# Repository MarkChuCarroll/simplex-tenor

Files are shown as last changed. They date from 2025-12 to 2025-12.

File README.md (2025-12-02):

# Mini-Tenor Guitar

3d image of the tenor guitar

This is a mini-sized 4-string tenor guitar, intended to be strung using either nylon strings, or extra-light
gauge metal strings.

Everything is printed, _except_:

* a set of tuners with 10mm posts. (I use [these](https://www.amazon.com/gp/product/B0789YL6JF/ref=ppx_yo_dt_b_search_asin_image?ie=UTF8&psc=1).)
* A set of light or extra-light steel tenor banjo or tenor guitar strings. These should
  be strings intended for a CGDA tuning.
* A 12 1/4 inch truss rod (I used [this from StewMac](https://www.amazon.com/gp/product/B07HPBZ3NH/ref=ox_sc_act_title_1?smid=A1BA2XBPZFTT2S&psc=1)).
* 2 m4x60mm screws to attach the neck to the body.
* 2 m4 hex nuts.
* a 4x1mm carbon fiber rod, used to reinforce the body inside of the vertical brace.

Assembly should be pretty obvious.

I recommend printing this from PLA. In my experiments, PLA is by far the
best material that I've tried. PETG has too much flexibility, which seems
to absorb some of the resonant vibrations in the body; ABS adhesion issues
leave tiny micro-gaps in the body which completely ruin the tone.

## The Model

I started with a model written in standard OpenSCAD. That was a bit of a mess; I rewrote it partially using the BOSL libraries for OpenSCAD, which was a big improvement, but I was still struggling to make it come out the way I wanted, because honestly, OpenSCAD is a pretty terrible language.

So I wrote my own 3d modelling language.

The latest version is implemented in [Simplex](https://github.com/MarkChuCarroll/simplex), a 3d modelling
language that I built on top of the Manifest library. This
version of the model is contained in the file "mtenor.s3d".

The running the simplex model through the interpreter, you'll
get a collection of products:

* `mtenor-out-body-tail.stl`: the bottom-most section of the body.
* `mtenor-out-body-center.stl`:  the center section of the body.
* `mtenor-out-body-neck.stl`: The section of the body where the neck
  is attached.
* `mtenor-out-fretboard-full.stl`: a single-piece fretboard for large printers.
* `mtenor-out-fretboard-[ab].stl`: the fretboard split into two pieces for
   printing on normal-sized 3d printers. This includes guide-holes where
   you can insert 5mm pieces of filament as alignment guides, and cutouts
   for registration/alignment with the neck. The registration pegs are
   included in `mtenor-out-mist_bits.stl`.
* `mtenor-out-neck-[abc].stl`: the neck, divided into three printable pieces.
  Like the fretboard, this includes registration holes to use filament to
  align the sections for gluing.
* `mtenor-out-misc_bits.stl`: support plates, registration pegs, and fretboard
  inlays for assembly/glue-up.
* `mtenor-out-assembled.stl`: An image of the fully-assembled guitar, to show
  how the pieces should line up.
* `mtenor-out-bridge.stl`: a set of three different bridges; choose the one that
  gives you the most comfortable string-action.
* `mtenor-out-stand.stl`: a work-in-progress stand for supporting the guitar
  when you're not playing it.

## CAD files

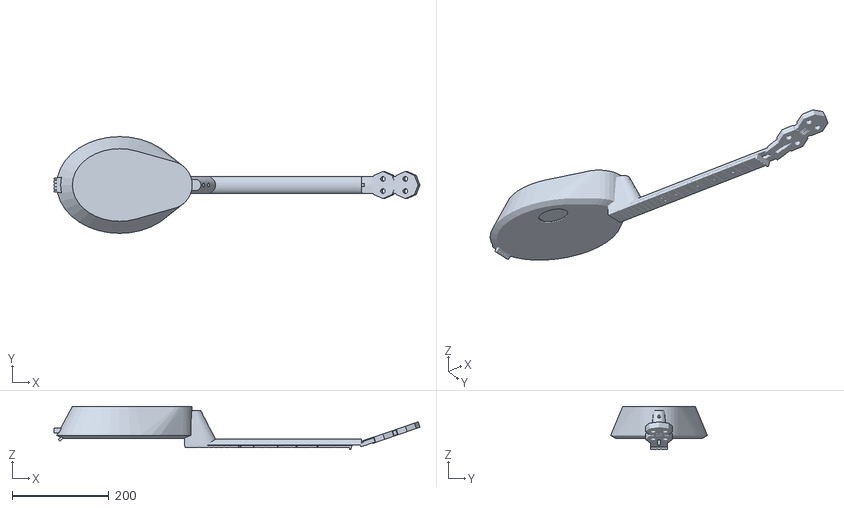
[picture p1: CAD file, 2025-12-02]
mtenor-out-assembled.stl
756.2 x 200.0 x 89.5

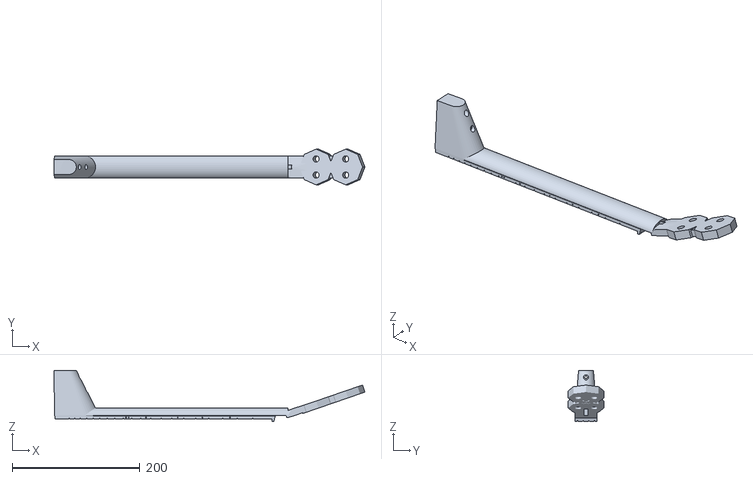
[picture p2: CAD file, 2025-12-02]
mtenor-out-fretboard-full.stl
487.5 x 56.0 x 80.5

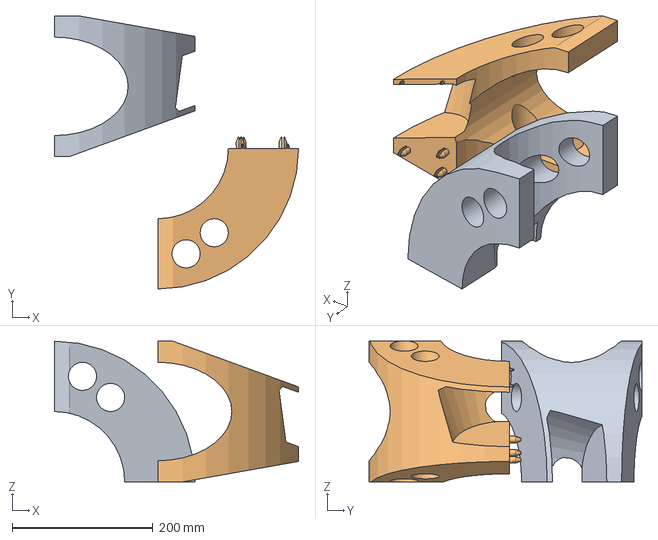
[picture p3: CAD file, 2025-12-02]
mtenor-out-neck-a.3mf
347.4 x 388.2 x 200.0 mm
mtenor-out-stand.stl x 2

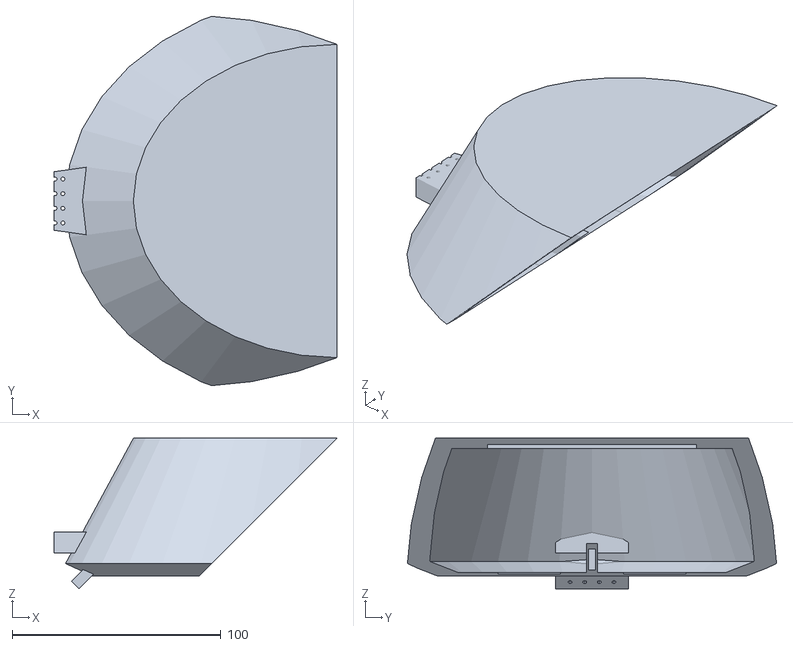
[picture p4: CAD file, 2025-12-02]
mtenor-out-body-tail.stl
135.5 x 176.8 x 72.1

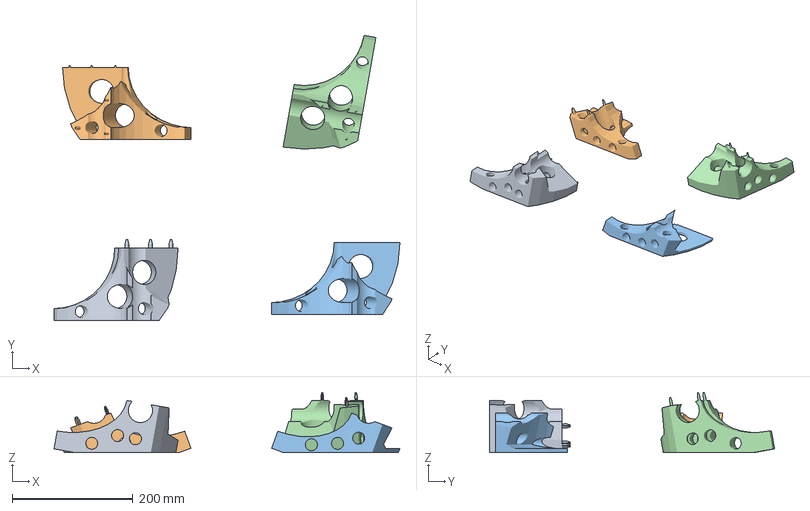
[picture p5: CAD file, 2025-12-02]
split-stand.3mf
573.4 x 472.7 x 99.8 mm
mtenor-out-stand-1.stl
mtenor-out-stand-2.stl
mtenor-out-stand-3.stl
mtenor-out-stand-4.stl

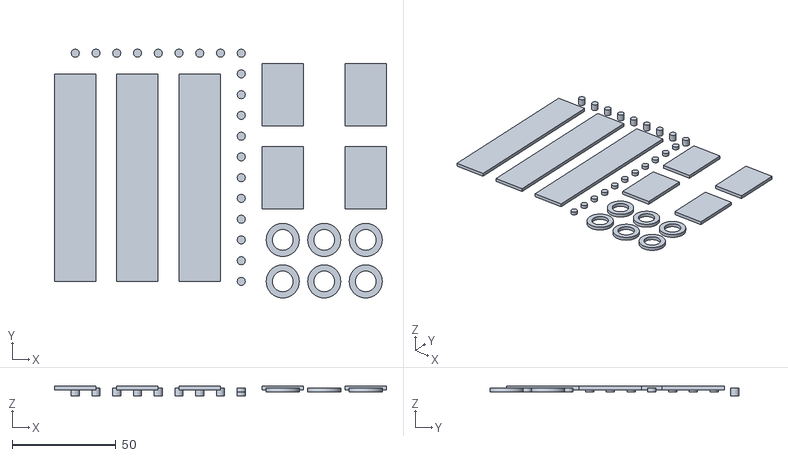
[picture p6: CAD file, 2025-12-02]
mtenor-out-misc_bits.stl
160.0 x 120.0 x 5.00

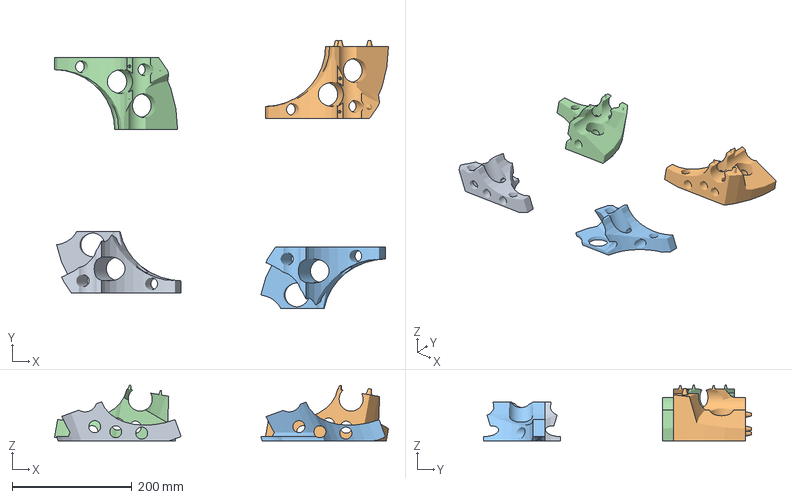
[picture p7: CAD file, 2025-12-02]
mtenor-out-stand-improved.3mf
557.9 x 447.3 x 93.3 mm
mtenor-out-stand.stl x 4

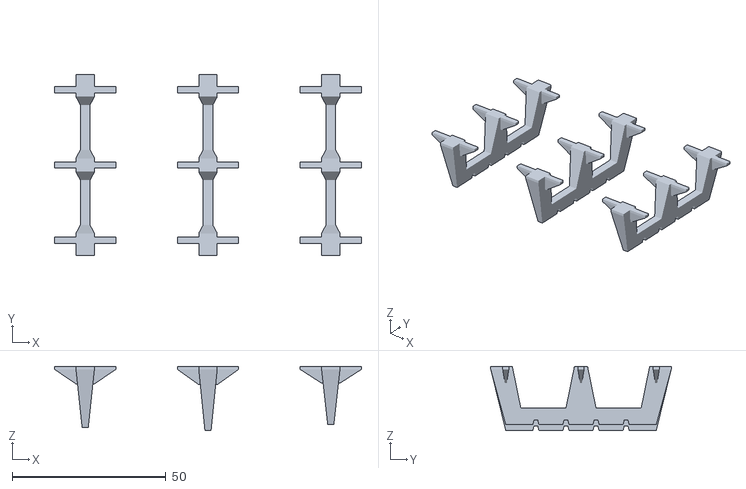
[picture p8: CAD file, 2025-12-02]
mtenor-out-bridge.stl
100.0 x 58.8 x 21.0

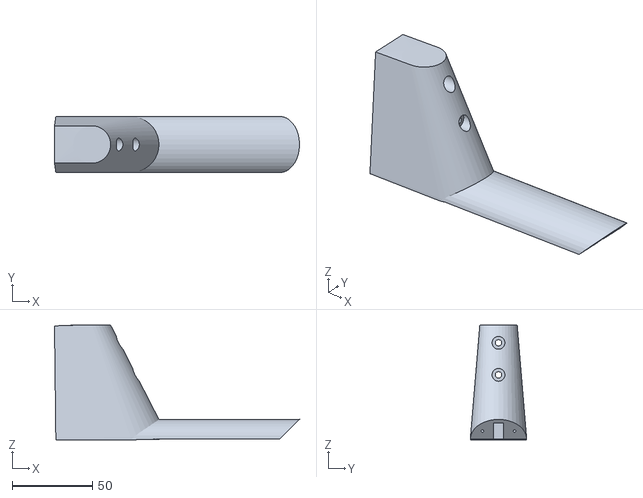
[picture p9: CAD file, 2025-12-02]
mtenor-out-neck-c.stl
152.7 x 35.0 x 71.5

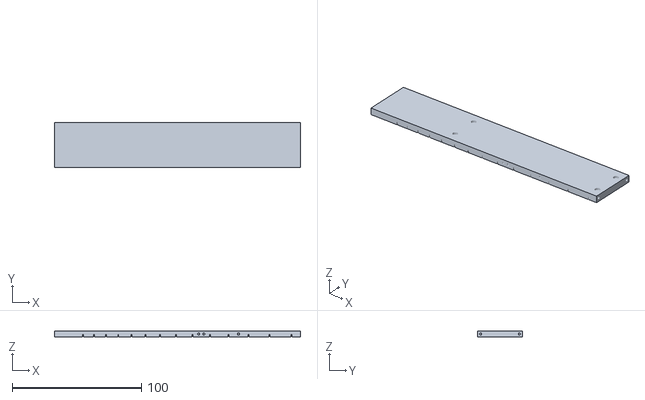
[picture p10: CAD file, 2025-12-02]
mtenor-out-fretboard-b.stl
190.1 x 35.0 x 5.00

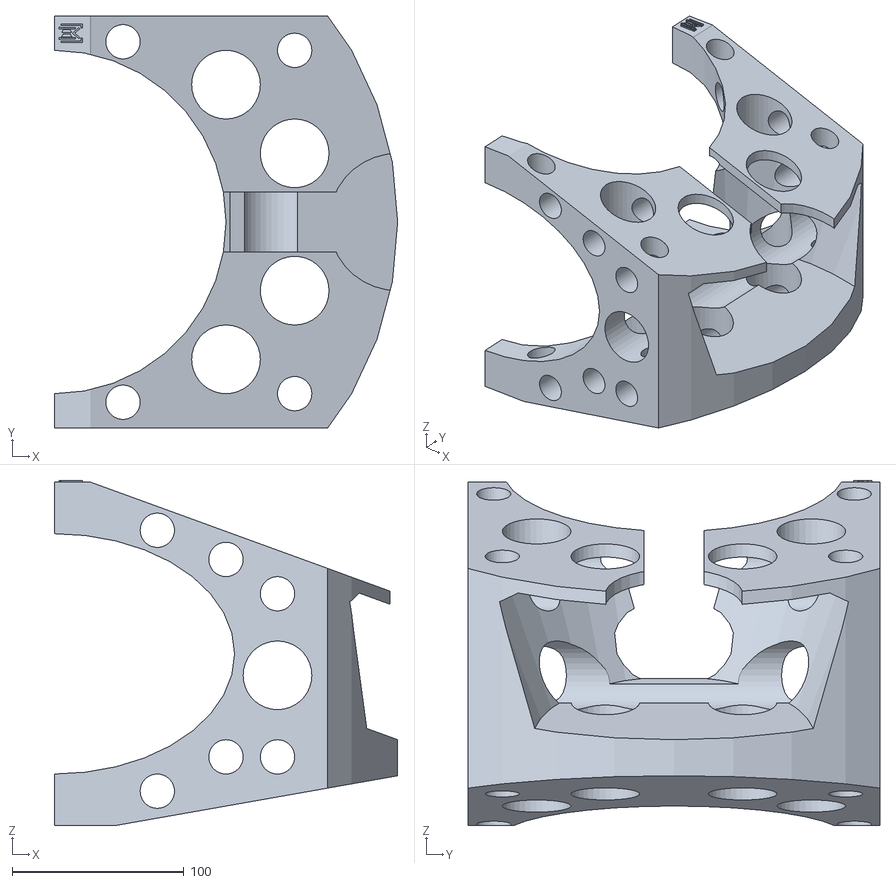
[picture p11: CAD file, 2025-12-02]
mtenor-out-stand.stl
200.0 x 240.0 x 201.0

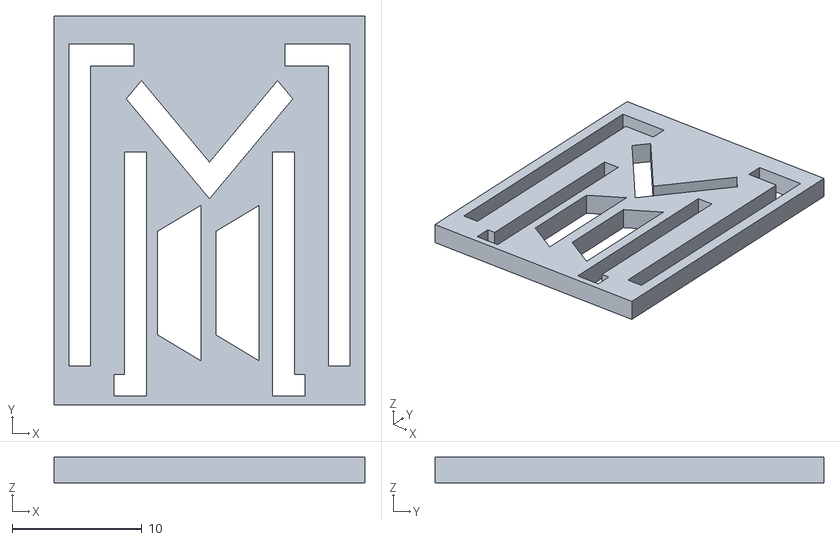
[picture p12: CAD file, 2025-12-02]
mark-out-plate.stl
24.0 x 30.0 x 2.00

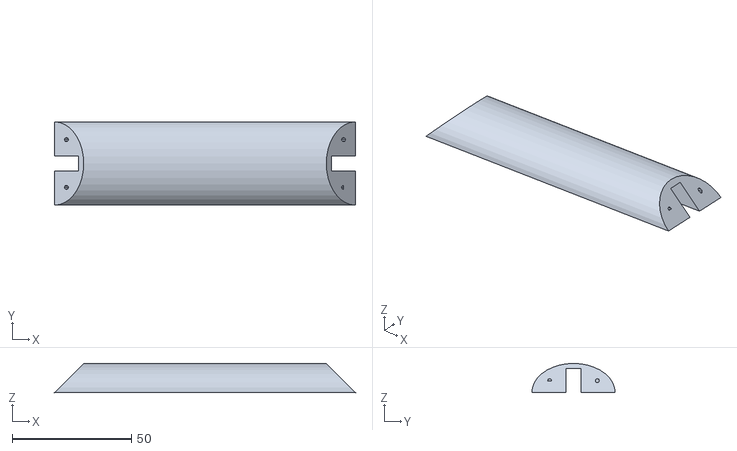
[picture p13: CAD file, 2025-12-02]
mtenor-out-neck-b.stl
126.4 x 35.0 x 12.2

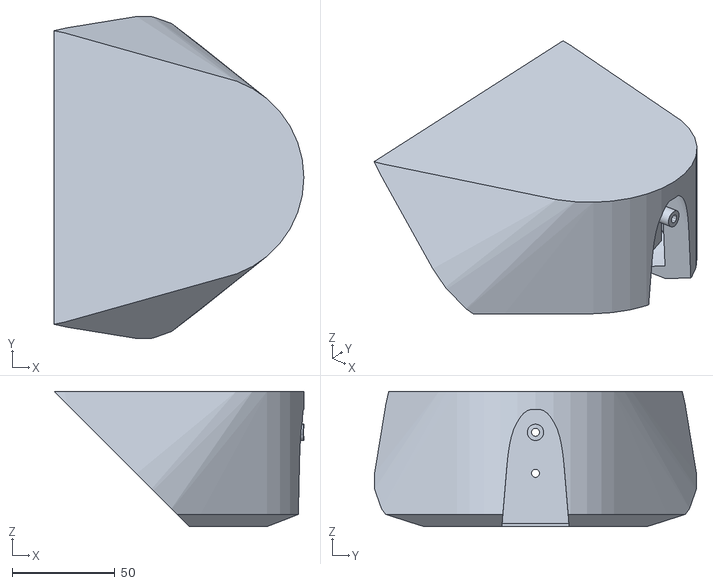
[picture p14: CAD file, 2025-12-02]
mtenor-out-body-neck.stl
121.7 x 156.9 x 66.0

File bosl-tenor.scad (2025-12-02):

//
// Copyright 2024 Mark C. Chu-Carroll
//
// Licensed under the Apache License, Version 2.0 (the "License");
// you may not use this model except in compliance with the License.
// You may obtain a copy of the License at
//
//     http://www.apache.org/licenses/LICENSE-2.0
//
// Unless required by applicable law or agreed to in writing, software
// distributed under the License is distributed on an "AS IS" BASIS,
// WITHOUT WARRANTIES OR CONDITIONS OF ANY KIND, either express or implied.
// See the License for the specific language governing permissions and
// limitations under the License.

include <BOSL2/std.scad>

/**
 * The body is teardrop shaped. It's built by setting up two
 * cylinders, one smaller than the other, with offset centers,
 * and then taking their hull. We add a bit of slant by making
 * the larger cylinder actually a bit conic, but square up at
 * the heel because the smaller is a true cylinder.
 * Then we round the edges by using minkowski sum with a little sphere.
 */

module body(size, thickness, split = false) {
  module body_shape(length, thickness) {
    // Anchoris the body top where the neck meets the body.
    //  translate([ 130, 0, -5 ])
    //  minkowski() {
    module outline() {
      hull() {
        scale([ 1.3, 1, 1 ]) {
          cylinder(thickness + 10, length, length * 3 / 4);
        }
        translate([ length, 0, 0 ]) {
          cylinder(thickness + 10, length / 2, length / 2);
        }
      }
    }

    translate([ 0, 0, -5 ]) {
      hull() {
        outline();
        translate([ 0, 0, -10 ]) scale([ 0.9, 0.9, 0.9 ]) outline();
      }
    }
  }

  /**
   * The screwblock is a section matching the back end of the neck's heel
   * block, which has holes and hex-nut slots to allow the neck to be
   * securely bolted on to the body.
   */
  module screwblock(radius, length, thickness) {
    /*
     * I want to put cutouts for hex nuts into the screw block.
     * For an m4 hex nut, the size flat-to-flat is 7mm.
     * So the rough outer radius of the hexnut is 5mm.
     */
    module hexnut_slot() {
      rotate([ 90, 0, 0 ]) {
        rotate([ 0, 0, 30 ]) {
          union() {
            translate([ 0, 0, 20 ]) {
              cylinder(40, 2.4, 2.4, center = true, $fn = 20);
            }
            linear_extrude(height = 3) { circle(5, $fn = 6); }
          }
        }
      }
    }

    // positions for the holes are 8mm from the base of the neck heel,
    // and 25mm from the base of the neck heel.
    // The neck heal is ??? mm off the bottom of the body.
    translate([ size * 1.2 + 14, 0, thickness * 0.8 + 5 ])
        rotate([ 0, 180, 90 ]) {
      elev = thickness * 0.8 + 5 + 1;

      difference() {
        linear_extrude(thickness + 11, scale = [ 1.5, 1 ], center = false) {
          translate([ -radius, 0, 0 ]) { square([ radius * 2, length / 2 ]); }
        }
        // formerly 16.8 and 28.8
        translate([ 0, length / 2, elev - 8 ]) hexnut_slot();
        translate([ 0, length / 2, elev - 25 ]) hexnut_slot();
      }
    }
  }

  module assembly() {
    union() {
      /**
       * We want the body to be hollow. So what we do is create
       * one copy of the body  form, and then a second scaled version that's a
       * bit smaller - and we subtract the smaller one from the larger.
       */

      difference() {
        body_shape(size, thickness);
        translate([ 0, 0, 1 ]) {
          scale([ 0.9, 0.9, 0.9 ]) { body_shape(size, thickness); }
        }

        // cut out the sound-hole.
        // TODO: don't cut so far down; it's cutting into the body side.
        move([ size / 2.0 - 5, -size / 2 + 5, -thickness / 2 ]) {
          scale([ 1.4, 1.0, 1.0 ]) { cylinder(size / 4, size / 4, size / 4); }
        }

        translate([ 0, 0, -20 ]) neck(neck_offset, scale, neck_width, true);
      }

      translate([ -20, 0, 0 ]) screwblock(neck_width * 2 / 6, 20, 45);

      // and the tailpiece.
      up(thickness / 3) left(size * 1.1) tapered_tailpiece(
          neck_width, neck_width / 4, neck_width / 1.5, neck_width / 6);

      // The string guide over the tailpiece.
      color("#ff00ff") translate([ -size * 1.25, 0, -12 ]) rotate([ 0, 45, 0 ])
          cuboid([ 2, neck_width * 1.2, 14 ], chamfer = 1);

      // internal bracing
      // CF rod is 1/8x3/8 - which is 3.175mmx9.525mm. Adding a bit of space
      // so that it can be slid in, we can make a slot that's 3.5mmx10mm.
      difference() {
        union() {
          down(12) color("#ff0000") prismoid([ 10, 155 ], [ 10, 120 ], 6);
          zrot(90) down(12) fwd(100) left(6) cube([ 12, 200, 15 ]);
        }
        zrot(90) down(7) fwd(95) left(3.5 / 2) cube([ 3.5, 190, 10 ]);

        // prismoid([ 12, 200 ], [ 10, 150 ], 15);
        // prismoid([ 3.5, 200 ], [ 3.5, 150 ], 10);
      }
    }
  }

  assembly();
}

/*
 * The neck gets pretty complicated.
 * We start with a half cylinder of the right length. To get the cross
 * section that we want, we then stretch its width by 1.3, and its
 * height and 1.2.
 *
 * Then we add the head. It'll probably get tweaked a bit to make it
 * prettier, but for now, it's a box set at a 20 degree declination
 * from the next, rounded at the back.
 *
 * Next, we add a heel, which I moved into another module.
 *
 * After the heel, we'll add the nut up at the top of the neck.
 *
 * Right next to the nut will be the fingerboard, with fret slots. (I
 * strongly prefer real  metal frets, so I'm just using slots, not
 * creating printed frets.
 */
module neck(offset, scale, width, solid = false) {
  neck_length = scale - offset;
  thickness = width / 2;

  /*
   * For creating the neck, it'll make things easier to start
   * with a half-cylinder.
   */
  module half_cylinder(radius, length) {
    union() {
      difference() {
        rotate([ 0, 90, 0 ]) { cylinder(length, radius, radius); }
        translate([ 0, -radius, -radius ]) {
          cube([ length * 3, radius * 2, radius ]);
        }
      }
    }
  }

  module neck_blank(width, length) {
    scale([ 1, 1.0, 0.8 ]) { half_cylinder(width / 2.0, length); }
  }

  module trussrod_cutout(length, neckwidth) {
    one_eighth_inch = 25.4 / 8;
    three_eighths_inch = 3 * one_eighth_inch;
    one_quarter_inch = one_eighth_inch * 2;
    one_sixteenth_inch = one_eighth_inch / 2;
    five_sixteenths_inch = 5 * one_sixteenth_inch;
    union() {
      // The main trussrod slot, running the full length of the neck.
      translate([ 0, -one_eighth_inch, -20 ])
          cube([ length, one_quarter_inch, three_eighths_inch + 20 ]);

      // The trussrod gets a little bit wider at the top, where the
      // screw mechanism is, so we need to broaden the cutout just
      // a little bit.
      translate([ length - 45, -three_eighths_inch / 2, -18 ]) {
        cube([ 45, three_eighths_inch, three_eighths_inch + 22 ]);
      }
      // And to reduce stress concentration, add a transition
      // between the wider and narrower parts.
      translate([ length - 45 + 1, 0, -0.5 ]) {
        color("#008888") rotate([ 0, -90, 0 ])
            prismoid(size1 = [ 29, three_eighths_inch ],
                     size2 = [ 20, one_quarter_inch ], h = three_eighths_inch);
      }

      translate([ length, 0, 4 ]) {
        rotate([ 0, 90, 0 ]) {
          scale([ 1.2, 1.6, 1.0 ]) cylinder(40, neckwidth / 5, neckwidth / 8);
        }
      }
    }
  }

  module heel(radius, length, thickness, drill = true) {
    translate([ radius - 5, 0, thickness ]) difference() {
      rotate([ 180, 0, 0 ]) {
        difference() {
          linear_extrude(thickness, scale = [ 2.0, 1.5 ], center = false) {
            circle(radius) left(radius) square(radius * 2, thickness);
          }
          translate([ -6 * radius, -radius * 2, 0 ]) {
            cube([ radius * 4, radius * 4, thickness ]);
          }

          if (drill) {
            translate([ -20, 0, 8 ]) {
              rotate([ 0, 90, 0 ]) { cylinder(70, 2.4, 2.4, $fn = 20); }
            }
            translate([ 10, 0, 8 ]) {
              rotate([ 0, 90, 0 ]) { cylinder(30, 5, 5); }
            }

            translate([ -20, 0, 25 ]) {
              rotate([ 0, 90, 0 ]) { cylinder(70, 2.4, 2.4, $fn = 20); }
            }
            translate([ 12, 0, 25 ]) {
              rotate([ 0, 90, 0 ]) { cylinder(30, 5, 5); }
            }
          }
        }
      }
    }
  }

  /**
   * The headstock.
   *
   * This took a ton of time to get to the point where it looks
   * good, and it's also functional. It's basically shaped from
   * two overlapping octagons. It gets thicker and a bit faceted
   * as it comes close to the neck joint.
   */
  module headstock(length, width, thickness) {
    // Anchor point is the center edge of the round section where the
    // headstock meets the body.

    module oct(diam) {
      intersection() {
        square([ diam, diam ], center = true);
        rotate([ 0, 0, 45 ]) square([ diam, diam ], center = true);
      }
    }
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

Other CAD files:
mtenor-out-body-center.stl
mtenor-out-fretboard-a.stl
mtenor-out-neck-a.stl
